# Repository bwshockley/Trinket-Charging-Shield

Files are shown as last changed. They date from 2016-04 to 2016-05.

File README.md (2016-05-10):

# Trinket-Battery-Shield
Adafruit Trinket Shield for Battery Charging and RGB status LED.

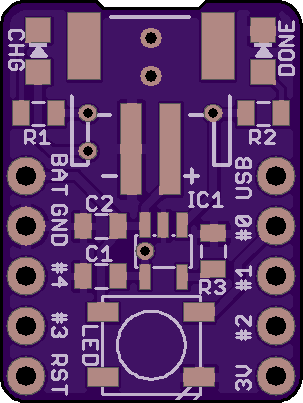
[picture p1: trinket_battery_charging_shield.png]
Trinket Battery Charging Shield Front

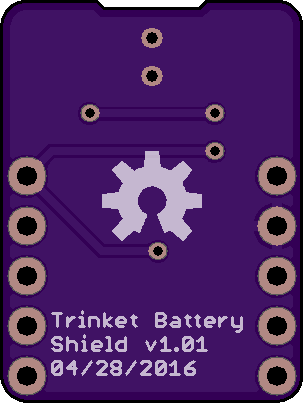
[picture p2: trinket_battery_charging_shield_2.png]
Trinket Battery Charging Shield Back


Version B

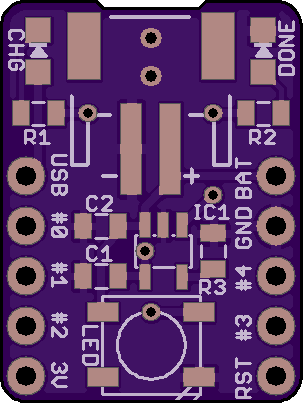
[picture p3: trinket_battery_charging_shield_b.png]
Trinket Battery Charging Shield Front

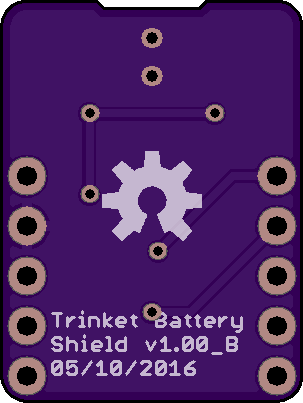
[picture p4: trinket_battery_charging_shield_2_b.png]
Trinket Battery Charging Shield Back


## About
This is an add-on circuit board for the [Adafruit Trinkets](https://www.adafruit.com/?q=trinket&).  This board adds a battery connector with an MCP73831 Lithium-Ion/Lithium-Polymer battery charger set at 100mAH charging.
The charger has two indicator LEDs, one to indicate the battery is currently charging from the micro-usb port on the Trinket, and the other to indicate when the battery has fully charged.

Version B of the board has the connections reversed such that this board and the Trinket can back connected "back-to-back" so that the reset button and from LEDs (On and #1) can be accessed.  BOM is identical.

## Boards
PCBs can be ordered direct [through OSHPARK.com](https://oshpark.com/shared_projects/fXX7IH66).

[Version B here.](https://oshpark.com/shared_projects/0WDgFbOp)

## WS2812B LED
There is a pad for a WS2812B RGB LED.  This LED is connected to data pin #0.  The user can leave this LED unpopulated if only battery charging capability is required.

## Battery Power
Note that the Adafruit Trinkets come with circuits for using the battery power and automatically switching between USB power and battery power as needed.  If the user only wishes to have battery power and not the charging capability, the user only needs to populate the JST 2-Pin connector on the back of the Trinket.

## BOM
C1, C2 = 0805 series SMT capcitors 10uF and at least 10V to be safe.
R1, R2 = 0805 resistors.  These resistors determine the current each status LED uses.  Charging LED should not sink more than 25mA, and Done LED should not source more than 35mA.
R3 = 0805 resistor at 10KOhm.  This sets the charger at 100mAh.  Other values possible.  Recommend 100mAh.

IC1 = MCP73831T battery charging IC.

J1 = JST-2_SMD - Available via Adafruit, Sparkfun, or Mouser.

LEDs = 0805 LEDs. Not necessary for circuit to work.  Recommended LEDS:

* SML-LX0805SOC-TR (Orange) Charging LED with R1 = 390Ohm minimum
* SML-LX0805SUGC-TR (Green) Charged or Done LED with R2 = 270Ohm minimum

WS2812B LED - Not necessary, but if the user chooses to add, LED must be 5050 size.

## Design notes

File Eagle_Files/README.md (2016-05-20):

#Eagle Files
All files were designed with CadSoft Eagle PCB Design v7.5 (Eagle).  These files are provided AS IS and are not to be used for commercial purpose.
CadSoft provides several licensing options for Eagle, including a [Freeware license](http://www.cadsoftusa.com/download-eagle/freeware/) and a
[commercial light](http://www.cadsoftusa.com/eagle-pricing/) license.  Additional information
can be found on the [CadSoft website](http://www.cadsoftusa.com)

#BRD and SCH
The BRD (Board) files are the physical board layout files and the SCH (Schematic) files are the schematic for the circuit.

#GERBERS
I will upload the latest GERBER files as soon as possible.  GERBER files are industry standard and can be sent to almost any PCB manufacturer.
They do not require the use of CadSoft Eagle to view and use.

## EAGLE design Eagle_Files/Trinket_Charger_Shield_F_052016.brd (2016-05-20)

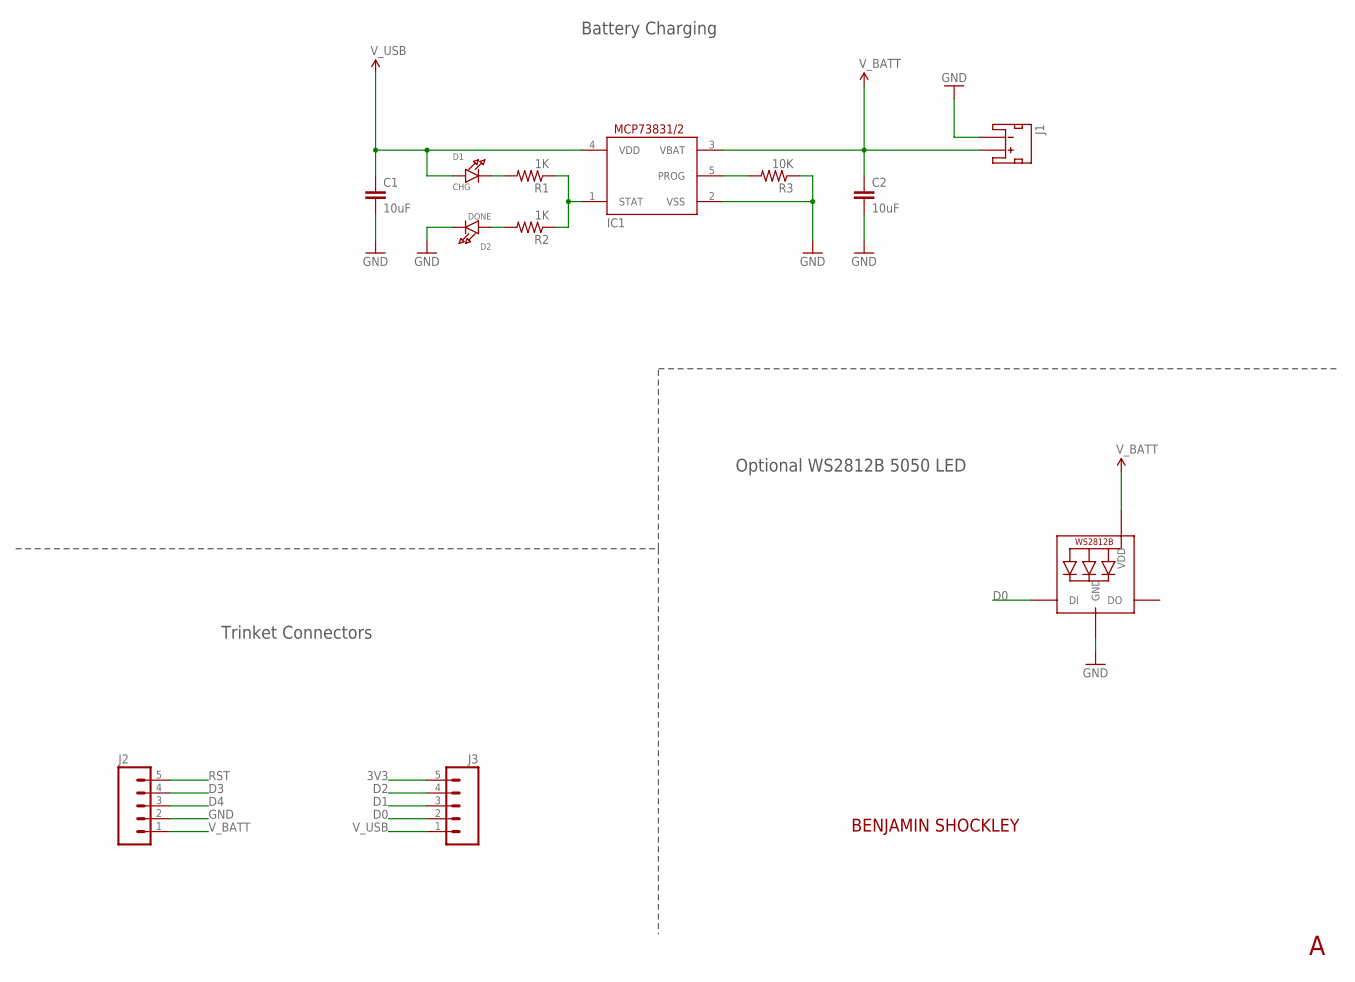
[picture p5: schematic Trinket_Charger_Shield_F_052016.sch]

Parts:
C1, C2: 10uF; 0805
D1: CHG; CHIPLED_0805_NOOUTLINE
D2: DONE; CHIPLED_0805_NOOUTLINE
IC1: MCP73831/OT; SOT23-5L
J1: JST_2MM_MALE; JST-2-SMD
J2, J3: M05NO_SILK; 1X05_NO_SILK
LED: WS2812B5050; WS2812B
R1, R2: 1K; 0805
R3: 10K; 0805

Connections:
3V3: J3.5
D0: J3.2, LED.4-DIN (DI)
D1: J3.3
D2: J3.4
D3: J2.4
D4: J2.3
GND: C1.2, C2.2, D2.C, IC1.2 (VSS), J1.1 (-), J2.2, LED.3-GND (GND), R3.1
unnamed: IC1.5 (PROG), R3.2
unnamed: IC1.1 (STAT), R1.1, R2.1
unnamed: D1.C, R1.2
unnamed: D2.A, R2.2
RST: J2.5
V_BATT: C2.1, IC1.3 (VBAT), J1.2 (+), J2.1, LED.1-VDD (VDD)
V_USB: C1.1, D1.A, IC1.4 (VDD), J3.1

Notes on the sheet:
Trinket Connectors
Optional WS2812B 5050 LED
Battery Charging

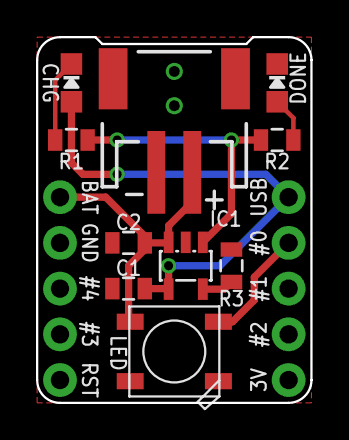
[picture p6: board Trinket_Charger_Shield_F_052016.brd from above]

Board: 2 copper layers, 15.2 x 20.3 mm, 13 parts (1 on the bottom side), 8 nets.

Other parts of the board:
U$1: OSHW-LOGO-M

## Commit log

2016-04-26 Initial Commit
    Initial commit for the Trinket Battery Charger Shield.
    [Trinket_Shield.brd, Trinket_Shield.sch, Trinket_Shield_battery.brd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]
2016-04-26 Create README.md
    Created the REDME file with background information and BOM for the circuit.
2016-04-26 Updated Schematic
    Updated schematic to include additional details and clean up design to
    clarify various parts of the circuit.
2016-04-26 Reroute LED VDD
    Rerouted the VDD to the WS2812B LED - Better grounding of the
    capacitors.
    [Trinket_Shield_battery.brd]
2016-04-26 Update USB Power to CHG LED
    Slight change in route of USB power to CHG LED.
    [Trinket_Shield_battery.brd]
2016-04-28 Added Images of Boards
    Added images of front and back of circuit board.
2016-04-28 Update README.md with Images
    Added images of the front and back of the circuit board to the README file.
2016-04-28 Updated Board Silk
    Added the OSHW Icon and some polarity indicators for the battery connector.
    [Trinket_Shield_battery.brd]
2016-05-09 Added PCB Link
    Added link to order PCBs on OSHPark.com
2016-05-10 Create Trinket_Charger_Shield_B
    This version is designed to connect to the trinket on the back side, so the two boards connect "back-to-back". this allows for continued use of the Trinket reset button and two front LEDs (on and #1).
    [Trinket_Charger_Shield_B.sch]
2016-05-10 Added Version B
    Updated to add information about Version B of the board.
2016-05-20 Uploaded latest files
    Uploaded the latest files with dates amended to file names for clarity. The shield files with the F indicate the board for the Front of the Trinket, while the files with the B indicate the board for 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
    [Trinket_Charger_Shield_B_051016.brd, Trinket_Charger_Shield_B_051016.sch, Trinket_Charger_Shield_F_052016.brd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]

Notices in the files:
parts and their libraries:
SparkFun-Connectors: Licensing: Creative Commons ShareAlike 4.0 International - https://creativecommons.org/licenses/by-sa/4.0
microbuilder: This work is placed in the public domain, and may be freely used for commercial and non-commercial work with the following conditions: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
